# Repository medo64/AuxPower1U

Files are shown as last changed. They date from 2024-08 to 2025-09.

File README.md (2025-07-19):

# AuxPower1U

This project is 1U enclosed case with 5 DC outputs that are separately
controllable via front momentary switches with LEDs.

Features:
* 5 DC inputs (input 1 has to be 9-15V)
* 5 DC outputs
* 5 separate button controls
* voltage and current monitoring (9-60V, 0-8A, per channel)
* temperature monitoring
* OLED output
* 3 power supplies
* 2 power inputs (one for UPS, one for non-UPS)

## Usage

Different functionality can be triggered by different key press lengths:
* <5 seconds:    detail mode for channel (turns off automatically in 60 seconds)
* 5-10 seconds:  reset once button is released (or turns on if output was turned off)
* 10-13 seconds: turn off output permanently
* >13 seconds:   ignore press

## Uart Communication

Current usage will be written to UART twice a second. See example below:

    1: 11.98V 0.40A   4.77W [ON]
    2: 15.40V 3.10A  47.74W [ON]
    3: 15.42V 0.00A   0.00W [OFF]
    4: 15.42V 0.00A   0.00W [OFF]
    5: 54.13V 0.00A   0.00W [OFF]
    T: 23.4C

Each line consists of the space-separated readings. If line starts with a
channel number (1-5), what follows will be readings for the given channel of
voltage (V), current (A), and power (W) followed by a channel status. If line
starts with a letter T, what follows is a temperature. Each line will end with
`CRLF`.

Commands can be given to device by sending command code followed by a channel.
Available commands are:
* `D`: Disable
* `E`: Enable
* `R`: Reset
* `I`: Information

For example, to disable channel 2 use:

    D2

### 3.5mm Uart Connector

This is pinout, as viewed from board side (i.e. as marked on board).

| JST | 3.5mm  | Signal |
|-----|---|---|
|  1  | Tip | RX |
|  2  | Sleeve | GND |
|  3  | Ring | TX |

## Test Mode

To enter test mode, keep buttons 1 and 5 pressed while powering board on. Each
subsequent press will then cycle through channel and show voltage/current values
in higher than normal resolution.

## Components

* [MainController](src/MainController/README.md): Allowing for monitoring and resetting of lines
* [AuxFanController](https://github.com/medo64/AuxFanController): Optional board to run PWM fans dependant on temperature
* [DellPowerTrigger](https://github.com/medo64/DellPowerTrigger): Emulating Dell charger for 5.5x2.1mm input

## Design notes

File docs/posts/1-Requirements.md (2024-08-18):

As part of my home server setup, I have a few devices that have "free-floating"
power supplies. For example, my modem, my wireless PoE adapters, and a few test
boxes all have their power supply pushed into rack's nooks and crannies. Even
worse, since I want to have the capability to reset them, they are connected via
[ResetBox](https://www.medo64.com/resetbox/) (or its [type-C variant](https://www.medo64.com/2023/05/type-c-power-delivery-as-passive-poe-source/))
making cable situation even messier. It's way beyond time to sort that out!

In this blog series, I will go over what's needed to design a nice 1U box that
can fit all (or as many as I can) different power supplies togethe. Their
outputs should be resettable by physical buttons on the device's front. Since I
actually didn't finish the project as I'm typing this, expect the series not
only to last a few months while I gather all necessary equipment but also for my
"specifications" to shift slightly as I discover new things or rethink my old
ways.

At first, let's look at what power supplies we have currently:
* `12V` `25W`: Arris SURFboard Modem
* `22V-57V` `20W`: Mikrotik hAP ac
* `24-57V` `30W`: Mikrotik Audience
* `12-28V` `40W`: Mikrotik hAP ax3
* `19.5V` `65W`: Dell OptiPlex 3050 Micro
* `12-19V` `65W`: Intel NUC
* `54V` `15W`: Netgear GS305EPP (150W max)

If I squint hard enough, there are three distinct power supplies to use there;
the first one being a simple 12V power supply for modem. Power usage will be
really low on this one, so any hardware we place will run from it too.

To the second power supply, I had to give a bit more thought. Without question,
it has to run of the UPS but its target voltage is a bit of an unknown.
Currently, I am running my hAP ac and Audience from a 20V type-C power supply,
and Audience doesn't seem to love it as any minor transient causes reset. And
yes, officially Audience doesn't run that low, but I got lucky, I guess.
Previously, I was running my WiFi routers on 48V and both were fine with that;
so there are my two daya points. Considering other devices, I was leaning toward
selecting 24V as a second power supply.

However, that leaves my NetGear PoE switch a bit of a loner and outside of The
Box. For it, I would need to provide a proper 55V PoE power supply or at least
48V if stars align. The downside of this approach is that it leaves my Mikrotik
hAP ax3 either on 12V or for the last, non-UPS power supply. But the upside is
that it allows for a bit of future-proofing.

That leaves 2 non-UPS computers. Why are they not using UPS? Well, in my setup,
UPS power is really limited and is reserved for only two categories: my main
server and my Internet delivery devices (modem, router, WiFi APs). Anything else
just needs to handle a power loss. These two computers fall into "anything else"
category.

Intel NUC, we can already see, is flexible with a power supply specification.
When it comes to standard industrial voltages, it can handle both 12V and 15V
inputs. However, it Dell bretheren officially are not that flexible. While there
is a possibility my 3050 micro would work on 15V, anything higher is a no-go.
And since Dell authenticates its chargers, to figure this out, I'd need to trick
it first into accepting such voltage - all of which smells like another
sub-project. :)

If Dell doesn't want to cooperate, the only way forward would be to use one of
many [buck modules](https://www.amazon.com/dp/B07HRBT529/) intended for RVs that
brings 24V to 19V. I would really like to avoid this, if possible, because the
last thing I need is yet another power supply. However, it's good to have
options. And yes, ideally, I would find a 19V power supply; but I have a feeling
that finding one that can be properly mounted inside a 1U case is not going to
happen.

This brings us to the following rough power supply distribution (with a bit of
derating on power specification):
* `12V` `150W` (`100W` if I kick out Mikrotik hAP ax3 from my network):
  - `25W`: Arris SURFboard Modem
  - `25W`: Control boards
  - `40W`: Mikrotik hAP ax3

* `15V`/`19V`/`24V` `200W` (`150W` should be realistically more than fine):
  - `65W`: Dell OptiPlex 3050 Micro
  - `65W`: Intel NUC

* `48V`/`55V` `100W` (going higher than this might be good for the future PoE devices):
  - `20W`: Mikrotik hAP ac
  - `30W`: Mikrotik Audience
  - `15W`: Netgear GS30s5EPP

There is an alternative at a bit lower voltage:

* `12V` `75W`
  - `25W`: Arris SURFboard Modem
  - `25W`: Control boards

* `15V`/`19V`/`24V` `200W` (`150W` should be realistically more than fine):
  - `65W`: Dell OptiPlex 3050 Micro
  - `65W`: Intel NUC

* `24V` `150W`
  - `20W`: Mikrotik hAP ac
  - `30W`: Mikrotik Audience
  - `40W`: Mikrotik hAP ax3

* Out-of-scope
  - `15W`: Netgear GS30s5EPP

I am strongly leaning toward option 1, but option 2 is a good alternative. And
yes, Mikrotik is not as power hungry as it seems above; I've never seen it reach
its maximum power usage. However, since I really love my network, I use those
numbers to bring an additional margin to the dimensioning process. If I find a
nice power supply that's slightly below what I need, I will get it and not worry
about it. But, before I get to that, this fudged accounting provides more
visibility into what brings the most value.

For various protection circuits, I', going to rely onto power supplies to
protect themselves. Thus, at minimum, I expect any selected power supply to have
over-voltage, over-current, short-circuit, and over-temperature protection
built-in.

When it comes to controlling this, I would say that ability to reset my Modem
and WiFi is a must. And these can be two buttons as I want to be able to
separately restart modem. For the hAP ax3, I don't care as much since it has
"under test" status in my network at this time. But let's argue that it needs to
be a separate button. At this time, I do control each of my computers inside the
rack via smart plug so moving them into The Box, I might want to see a button
for each, but I wouldn't really mind if both go down at the same time. This
brings the total number of reset buttons to somewhere between a minimum of three
and a maximum of seven.

Lastly, this blog post leaves us with the following action items I will probably
get around to solving:
* Chck can Netgear GS305EPP work on 48V
* Make trigger board for Dell
* Check does Dell Optiplex 3050 Micro work on 15V

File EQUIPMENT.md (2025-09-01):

## Equipment Setup

| Machine | Connector | Specification | Tested | Using | UPS | Btn | Color  | Resistor |
|---|---|---|---|--- |-----|-----|---|---|
| Arris SURFboard SB6141 | 2.1x5.5mm | 12V 2A 25W | - | 12.0V |  Y  |  1  | Red |  1,200 Ω |
| Mikrotik Chateau Pro ax | 2.1x5.5mm PoE | 18-57V 18W | - | 54.0V |  Y  |  2  | Orange | 270 Ω |
| Mikrotik wAP ax | 2.1x5.5mm PoE | 12-57V 9W | - | 54.0V |  Y  |  2  | | |
| NetGear GS305EPP | 6.3x3.0mm | 54V 2.4A 138W | - | 54.0V |  Y  |  3  | Green  |  3,000 Ω |
| Dell OptiPlex 3050 B082MN2 | 4.5x3.0mm | 19.5V 65W | 14-20V | 16.0V |  N  |  4  | Blue |  1,000 Ω |
| Intel NUC 5i3RYB | 5.5x2.5mm | 12-19V 65W | - | 16.0V |  N  |  5  | White  |  1,500 Ω |

## Not Used

| Machine | Connector | Specification | Tested |
|---|---|---|---|
| Mikrotik hAP ax3 | 2.1x5.5mm | 18-28V 38W | - |

## Wire Colors

* DC GND      (Black  18 AWG)
* DC 12V      (Yellow 18 AWG)
* DC 15V      (Orange 18 AWG)
* DC 55V      (Red    18 AWG)
* AC Hot      (Blue   18 AWG)
* AC Neutral  (White  18 AWG)
* AC Ground   (Green  16 AWG)

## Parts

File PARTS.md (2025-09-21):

## AuxPower PCB

### Properties

| | |
|---|---|
| Size | 90.0 x 90.0 mm ~ 15.2 sqin |

### Parts

|  # | Part name | RefDes | Source |
|---:|---|---|---|
|  5 | AT PhotoMOS 6A 60V [AQZ202G] (SIP-4) | AT1-AT5  | 255-5699-ND |
|  5 | C 100nF X7R 50V (0805) | C1-c5 | 478-5311-1-ND |
|  2 | C 1uF X7R 25V (0805) | C6-C7 | 1276-1066-1-ND |
| 12 | DS LED Red (3mm) | DS1-DS12 | 754-1218-ND |
|  5 | J Phoenix MC 1,5/ 2-G-3,81 R/A (2w) | J1-J5 | ED2808-ND |
|  5 | J Phoenix MC 1,5/ 4-G-3,81 R/A (4w) | J6-J10 | ED2810-ND |
|  5 | J JST XH r/a (3w) | J11-J15  | 455-S3B-XH-A-ND |
|  1 | J JST XH (3w) | J16 | 455-2248-ND |
|  1 | J JST XH (4w) | J17 | 455-B4B-XH-A-ND |
|  5 | R 0.025 1% 3W (2512) | R1-R5 | CRA2512-FZ-R025ELFCT-ND |
|  5 | R 470 1% 0.125W (0805) | R6-R10 | RMCF0805FT470RCT-ND |
|  5 | R 1.5K 1% 0.125W (0805) | R11-R15  | RMCF0805FT1K50CT-ND |
| 20 | R 3.3K 1% 0.125W (0805) | R16-R35  | RMCF0805FT3K30CT-ND |
|  5 | R 6.19K 0.1% 0.125W (0805) | R36-R40  | P6.19KDACT-ND |
|  1 | R 6.80K 0.1% 0.125W (0805) | R41 | P6.8KDACT-ND |
|  1 | R 102K 0.1% 0.125W 1% (0805) | R42 | P102KDACT-ND |
|  5 | R 390K 0.1% 0.125W (0805) | R43-R47  | P390KDACT-ND |
|  5 | U CurrentMonitor [HV7801] (SOT23-5) | U1-U5 | HV7801K1-GCT-ND |
|  1 | U Micro [PIC18F26K83] (SOIC-28) | U6 | PIC18F26K83-I/SO-ND |
|  1 | U Expander I2C [PI4IOE5V6416LEX] (TSSOP-24) | U7 | PI4IOE5V6416LEXDICT-ND |
|  1 | U Temperature Analog 2% [MCP9701A] (SOT23-3) | U8 | MCP9701AT-E/TTCT-ND |
|  1 | VR Linear 5V 1A [AS7805ADTR-G1] (TO252-2) | VR1 | AS7805ADTR-G1DICT-ND |
|  5 | P Phoenix MC 1,5/ 2-ST-3,81 (2w) | P1-P5 | ED2875-ND |
|  5 | P Phoenix MC 1,5/ 4-ST-3,81 (4w) | P6-P10 | ED2877-ND |

### Pin Usage (PIC18F26K83)

|  # | Pin | ICSP | Function | Description |
|---:|:---:|---|---|---|
|  1 | RE3 | MCLR | | |
|  2 | RA0 | | ANA0 | Out 1: Current (ADC 1.024V 1:5) |
|  3 | RA1 | | ANA1 | Out 1: Voltage (ADC 1.024V 16mV/bit; 1:64) |
|  4 | RA2 | | ANA2 | Out 2: Current (ADC 1.024V 1:5) |
|  5 | RA3 | | ANA3 | Out 2: Voltage (ADC 1.024V 16mV/bit; 1:64) |
|  6 | RA4 | | ANA4 | Out 3: Current (ADC 1.024V 1:5) |
|  7 | RA5 | | ANA5 | Out 3: Voltage (ADC 1.024V 16mV/bit; 1:64) |
|  8 | Vss | GND  | - | - |
|  9 | RA7 | | ANA7 | Out 4: Current (ADC 1.024V 1:5) |
| 10 | RA6 | | ANA6 | Out 4: Voltage (ADC 1.024V 16mV/bit; 1:64) |
| 11 | RC0 | | ANC0 | Out 5: Current (ADC 1.024V 1:5) |
| 12 | RC1 | | ANC1 | Out 5: Voltage (ADC 1.024V 16mV/bit; 1:64) |
| 13 | RC2 | | ANC2 | Temperature sensor (ADC 2.048V 0.02C/bit)  |
| 14 | RC3 | | ANC3 | In 1: Voltage  (ADC 1.024V 4mV/bit; 1:16)  |
| 15 | RC4 | | C4 | Out 5: Control |
| 16 | RC5 | | C5 | Out 4: Control |
| 17 | RC6 | | C6 | Out 3: Control |
| 18 | RC7 | | C7 | Out 2: Control |
| 19 | Vss | GND  | - | - |
| 20 | Vdd | 5V | - | - |
| 21 | RB0 | | B0 | Out 1: Control |
| 22 | RB1 | | I2C SCL  | I2C |
| 23 | RB2 | | I2C SDA  | I2C |
| 24 | RB3 | | B3 | LED: Activity |
| 25 | RB4 | | UART TX  | UART |
| 26 | RB5 | | UART RX  | UART |
| 27 | RB6 | CLK  | | |
| 28 | RB7 | DAT  | | |

### Pin Usage (PI4IOE5V6416)

|  # | Pin | ICSP | Description |
|---:|:-----:|---|---|
|  1 | INT | | - |
|  2 | Vdd/I | 5V | - |
|  3 | RESET | | - |
|  4 | P0_0  | | ~~Out 1: Control~~ |
|  5 | P0_1  | | ~~Out 2: Control~~ |
|  6 | P0_2  | | ~~Out 3: Control~~ |
|  7 | P0_3  | | ~~Out 4: Control~~ |
|  8 | P0_4  | | ~~Out 5: Control~~ |
|  9 | P0_5  | | |
| 10 | P0_6  | | Button 5: ~Switch  |
| 11 | P0_7  | | Button 5: LED |
| 12 | Vss | GND  | - |
| 13 | P1_0  | | Button 4: LED |
| 14 | P1_1  | | Button 4: ~Switch  |
| 15 | P1_2  | | Button 3: LED |
| 16 | P1_3  | | Button 3: ~Switch  |
| 17 | P1_4  | | Button 2: LED |
| 18 | P1_5  | | Button 2: ~Switch  |
| 19 | P1_6  | | Button 1: LED |
| 20 | P1_7  | | Button 1: ~Switch  |
| 21 | Vss | GND  | - |
| 22 | SCL | | I2C SCL |
| 23 | SDA | | I2C SDA |
| 24 | Vdd/P | 5V | - |

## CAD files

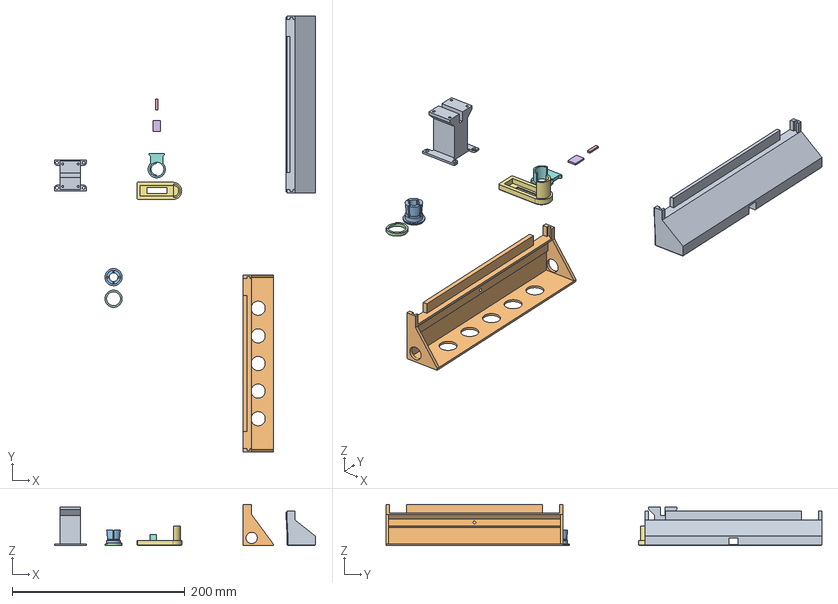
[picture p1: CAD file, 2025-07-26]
models/Cheval-PF19AL1UD1/AuxPower1U.FCStd
302.5 x 505.0 x 48.0 mm
PsuRailBack
PsuRailFront
AcGrommetBase
AcGrommetRing
OledBraceNarrow
OledBraceWide
OledBraceOuter
OledBraceInner
Fan

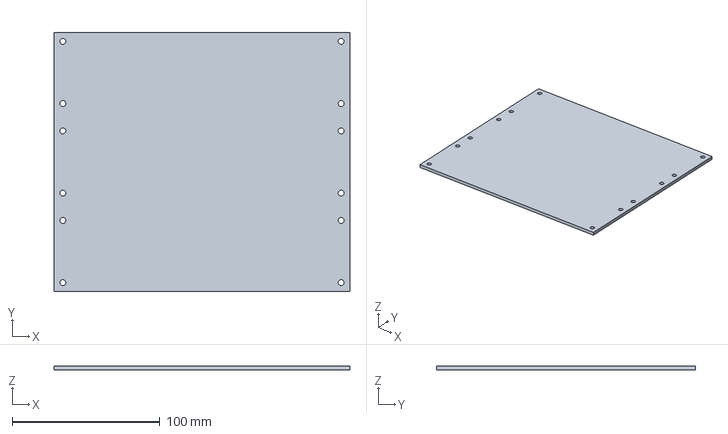
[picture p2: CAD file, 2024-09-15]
src/case/AuxPower1U Aluminium Plate.FCStd
200.0 x 175.0 x 3.00 mm

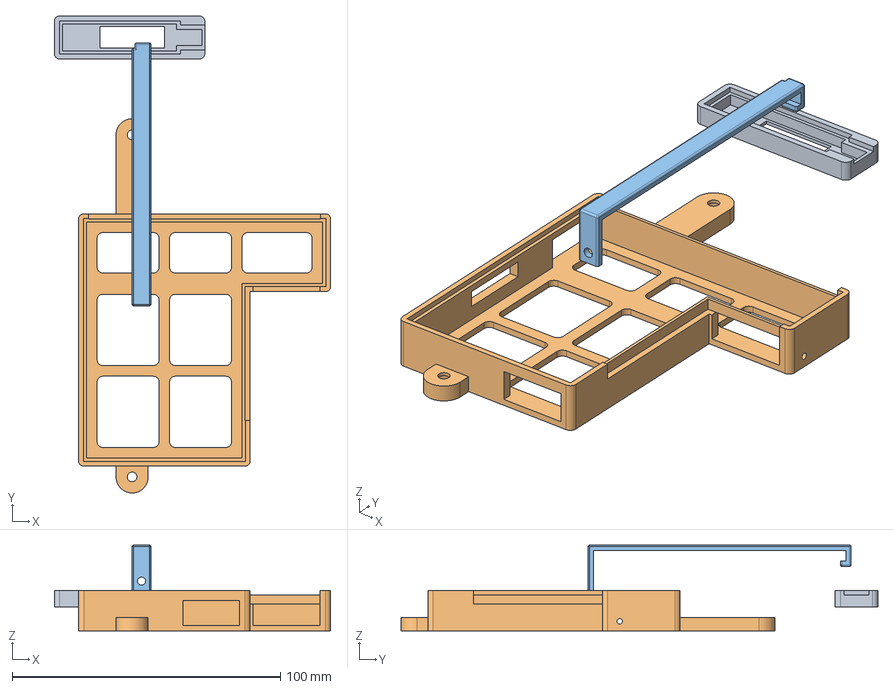
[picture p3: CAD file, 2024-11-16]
src/case/Bud-PRM14460/AuxPower1U PCBs.FCStd
103.0 x 177.7 x 32.0 mm
FanController
MainController
MainControllerBrace

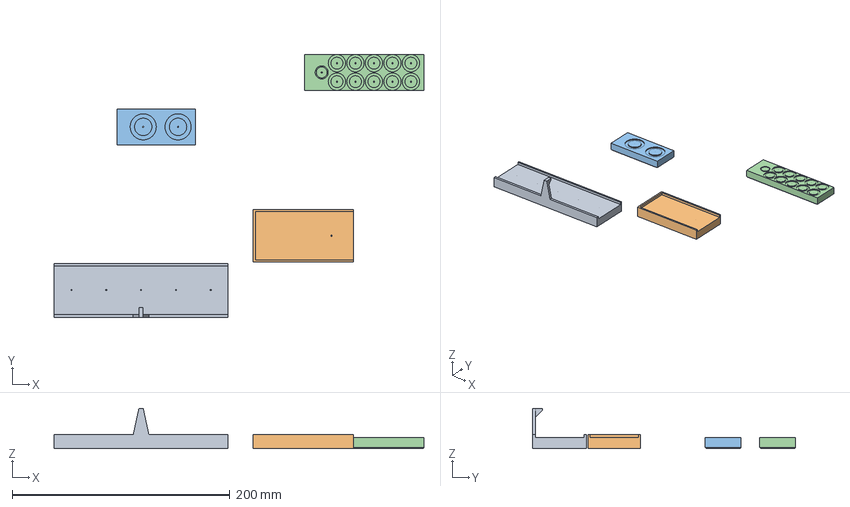
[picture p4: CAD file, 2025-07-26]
src/case/Cheval-PF19AL1UD1/AuxPower1U-Template.FCStd
340.0 x 241.7 x 37.0 mm
Buttons
Oled
AC
DC

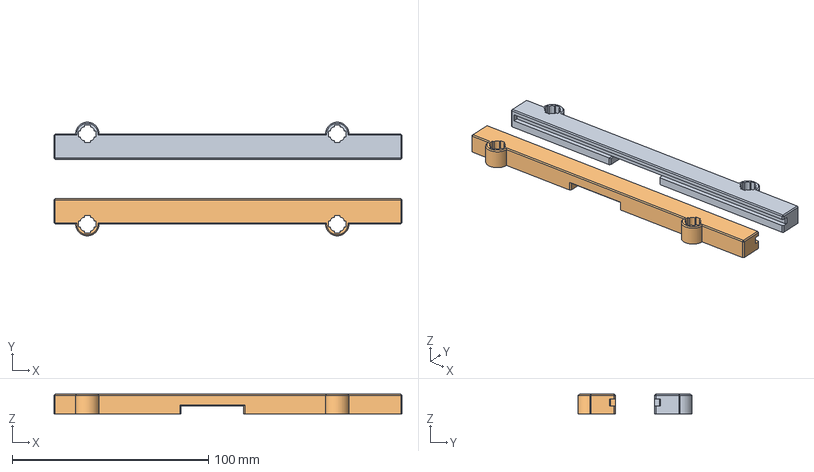
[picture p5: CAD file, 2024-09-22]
src/case/Bud-PRM14460/AuxPower1U PSRail.FCStd
177.4 x 58.0 x 10.0 mm
RailL
RailR

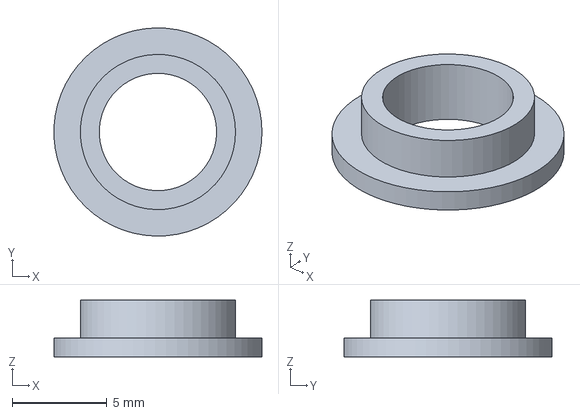
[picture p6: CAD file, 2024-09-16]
src/case/Bud-PRM14460/AuxPower1U Fixup.FCStd
11.0 x 11.0 x 3.00 mm

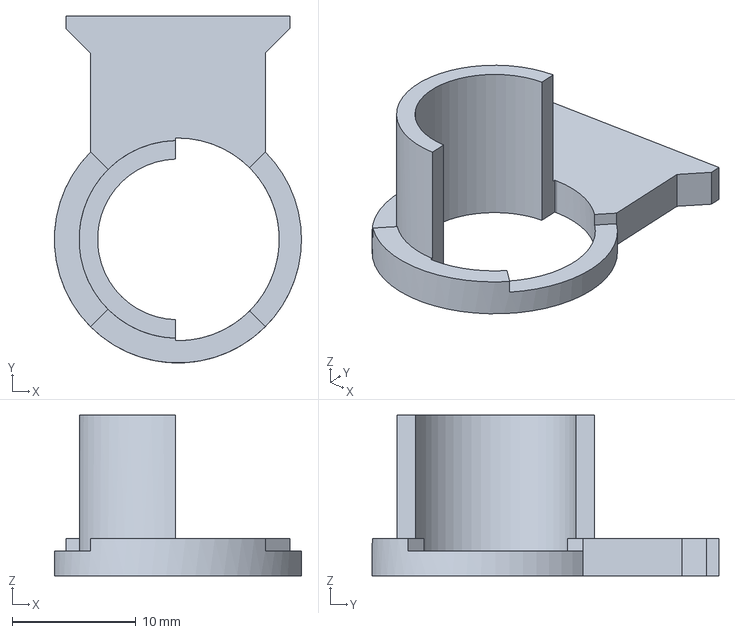
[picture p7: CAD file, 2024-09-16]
src/case/Bud-PRM14460/AuxPower1U OLED.FCStd
20.0 x 28.1 x 13.0 mm

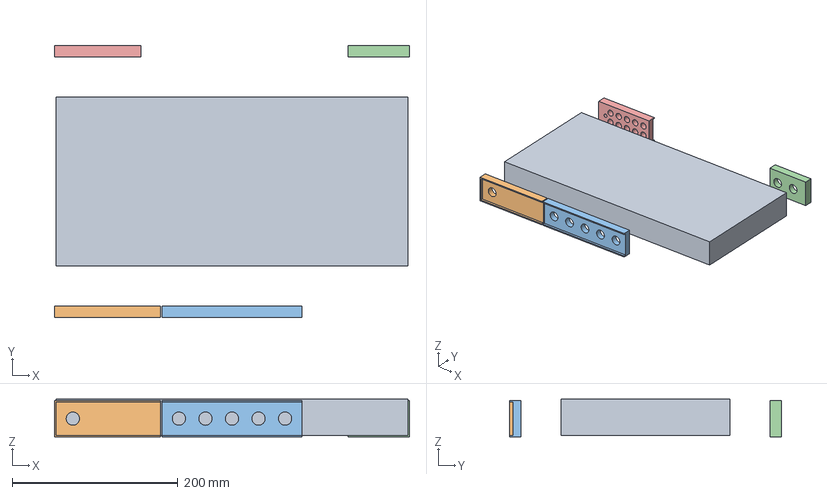
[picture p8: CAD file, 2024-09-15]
src/case/Bud-PRM14460/AuxPower1U Drill Template.FCStd
427.9 x 328.0 x 45.7 mm
Case
Front-Oled-16mm
Front-Buttons-16mm
Back-AC-16mm
Back-DC-11mm-6mm

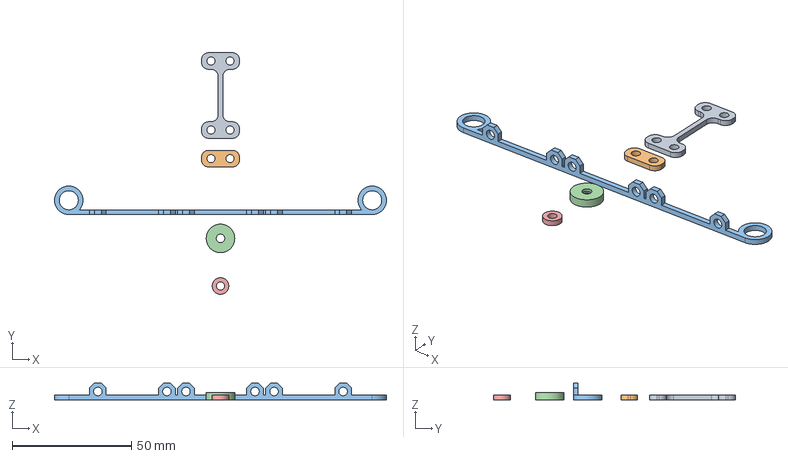
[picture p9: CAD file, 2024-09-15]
src/case/Bud-PRM14460/AuxPower1U Fan.FCStd
139.4 x 101.5 x 7.00 mm
LongBrace
ShortBrace
BackBrace
BraceCap
SingleBrace

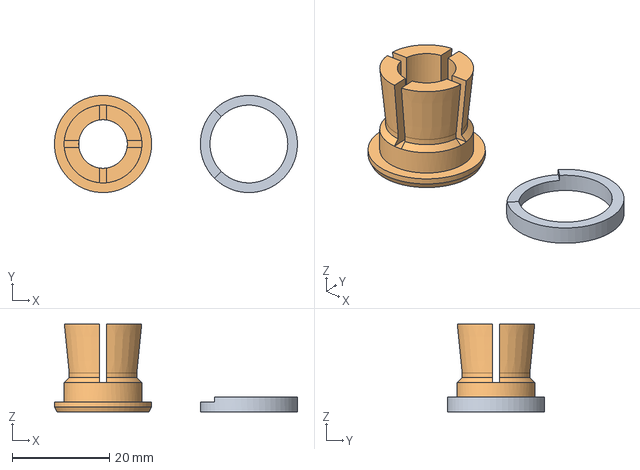
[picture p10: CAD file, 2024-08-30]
src/case/Bud-PRM14460/AuxPower1U AC Grommet.FCStd
50.0 x 20.0 x 18.0 mm
Ring
Base

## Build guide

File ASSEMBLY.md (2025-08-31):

## Enclosure Assembly

|  # | Part | Source |
|---:|---|---|
|  1 | Cheval PF19AL1UD1 | https://www.amazon.com/dp/B0F9W3KV6V |
| 10 | Panel DC 5.5x2.1mm Φ11mm | https://www.digikey.com/en/products/detail/tensility-international-corp/10-03609/12090912 |
| 20 | Crimp Terminal E7508 | |
|  1 | Panel Audio TRS 3.5mm Φ10mm | https://www.digikey.com/en/products/detail/tensility-international-corp/10-02844/11193625 |
|  1 | Spacer M3x30mm | https://www.amazon.com/dp/B0CZ3YTVWX |
|  1 | Machine screw M3x10 | |
|  1 | PSU rail back | 3D Printer |
|  1 | PSU rail front | 3D Printer |

### Power Supply Subassembly

|  # | Part | Source |
|---:|---|---|
|  1 | Power supply UHP-200-12 | https://www.digikey.com/en/products/detail/mean-well-usa-inc/UHP-200-12/7707237 |
|  1 | Power supply UHP-200-15 | https://www.digikey.com/en/products/detail/mean-well-usa-inc/UHP-200-15/7707238 |
|  1 | Power supply UHP-200-55 | https://www.digikey.com/en/products/detail/mean-well-usa-inc/UHP-200-55/13245670 |
|  1 | Aluminium plate 200x175 | SendCutSend (200x175 mm, 12 4mm holes, 6061 3.2mm, deburring) |
| 12 | Machine screw M3x6 | |
| 12 | Nut M3 | |
| 24 | Washer M3x6x0.5 | |
| | Heat sink compound | https://www.super-lube.com/silicone-heat-sink-compound-98003 |

### Fan Subassembly

|  # | Part | Source |
|---:|---|---|
|  2 | Fan 12V 3628 | https://www.aliexpress.us/item/3256804458184414.html |
|  4 | Fan screw | |
|  1 | Machine screw M3x8 | |
|  2 | Fan holder | 3D Printer |

### AC Power Wiring

|  # | Part | Source |
|---:|---|---|
|  2 | Power Cable AWG 18 | |
|  3 | Wago 221-413 | |
|  2 | Clamp 16mm | https://www.amazon.com/dp/B0C4V84F1V |
|  9 | Ring Terminal RV1.25-4s | https://www.aliexpress.us/item/3256805890650511.html |
| | Wire AWG 18 | |
|  2 | AC Grommet | 3D Printer |

### Buttons Subassembly

|  # | Part | Source |
|---:|---|---|
|  5 | Button 16mm | https://www.aliexpress.us/item/3256804791551109.html |
| 20 | Ferrule E7508 0.75mm² | |

### DC Power Wiring

|  # | Part | Source |
|---:|---|---|
| 12 | Ring Terminal RV1.25-4s | https://www.aliexpress.us/item/3256805890650511.html |
| 12 | Crimp Terminal E7508 | |
| | Wire AWG 18 | |

### OLED Subassembly

|  # | Part | Source |
|---:|---|---|
|  1 | OLED 128x32 | |
|  1 | Clamp 16mm | https://www.amazon.com/dp/B0C4V84F1V |
|  1 | OLED Grommet | 3D Printer |

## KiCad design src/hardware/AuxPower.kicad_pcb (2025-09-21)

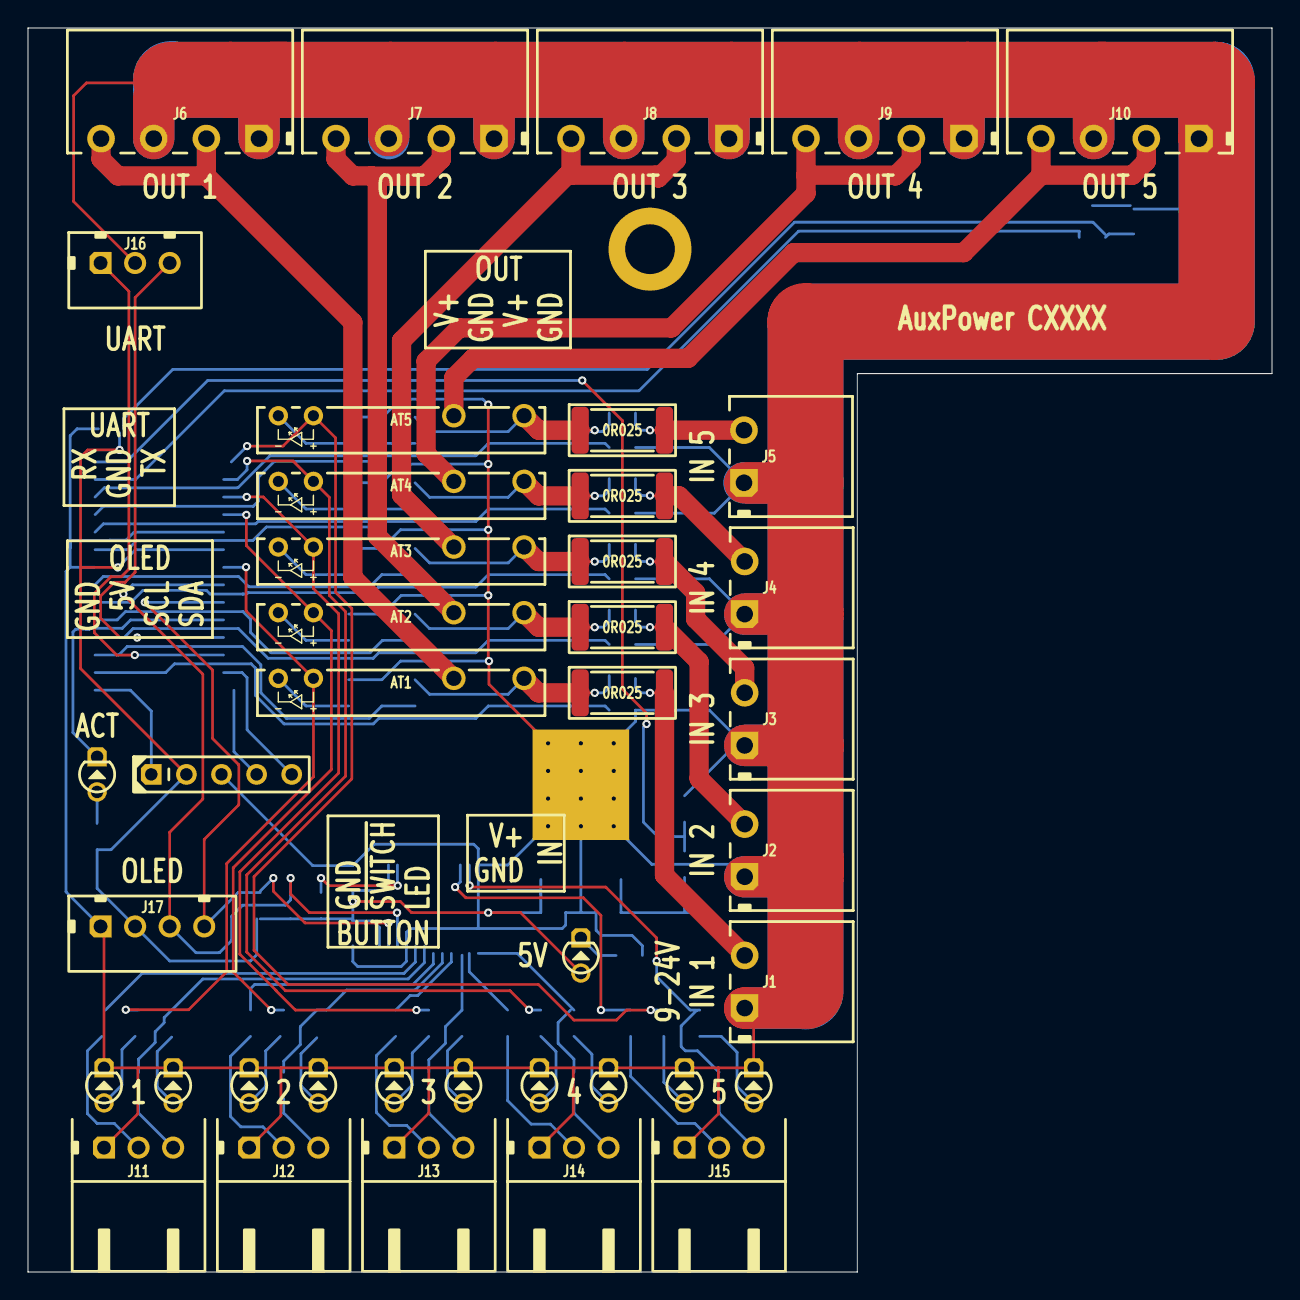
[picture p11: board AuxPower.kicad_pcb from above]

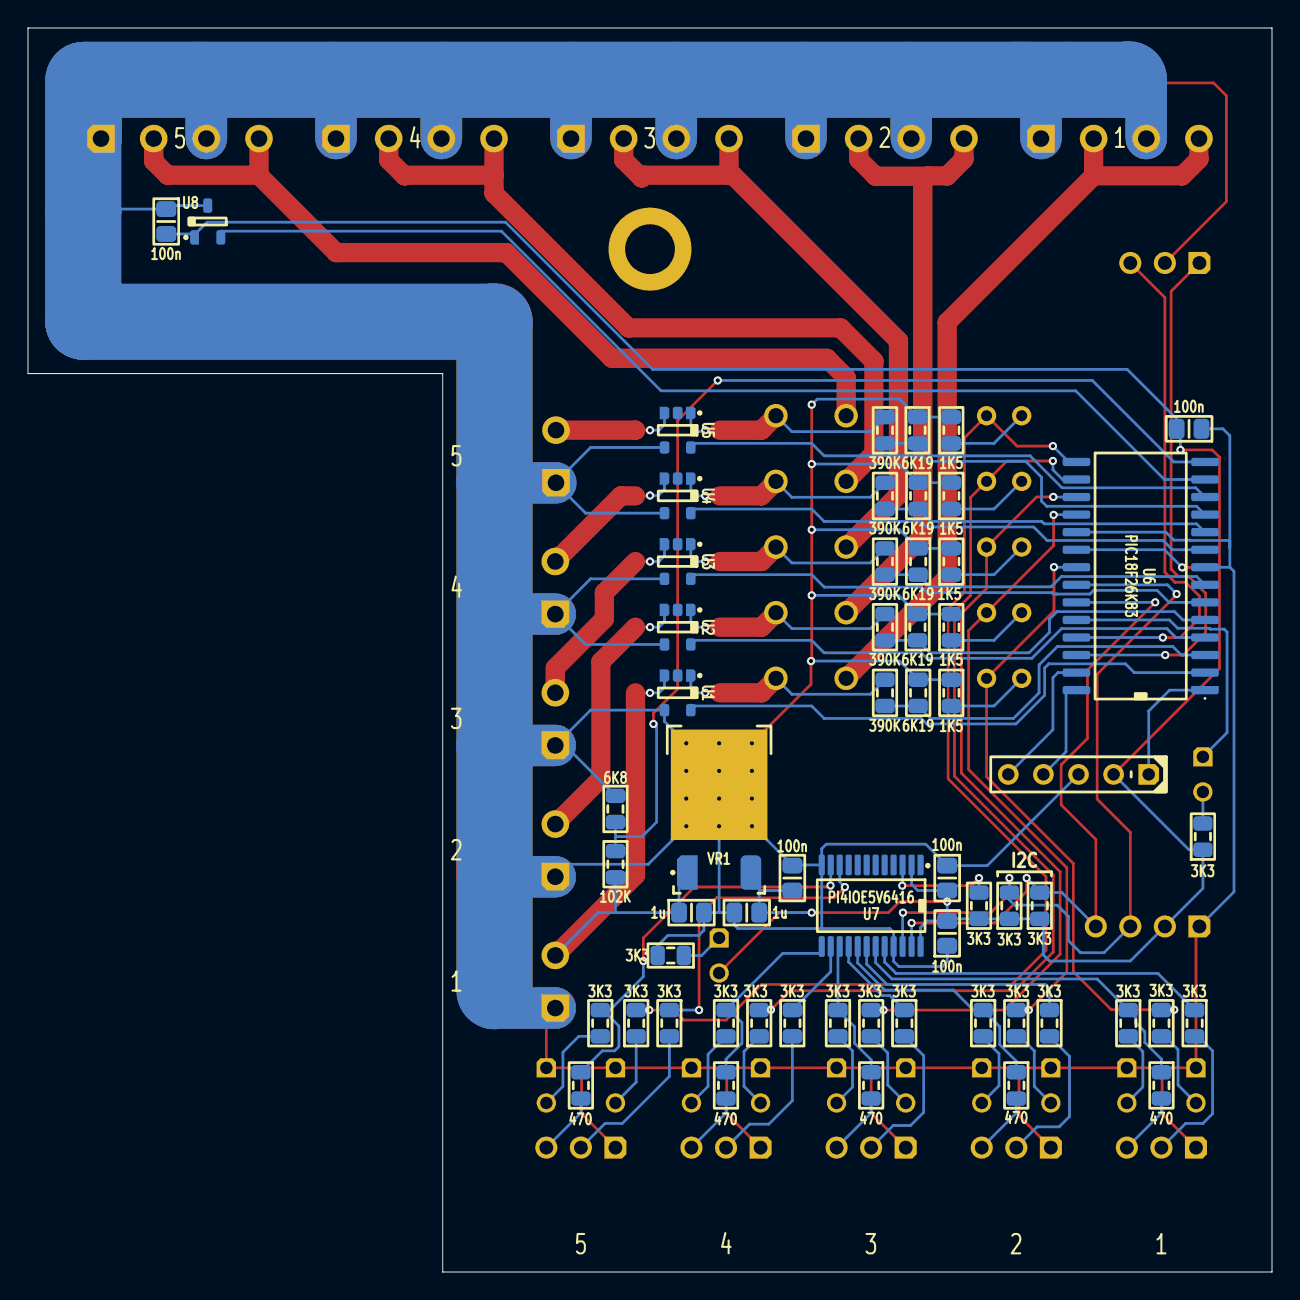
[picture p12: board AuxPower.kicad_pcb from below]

Board: 2 copper layers, 90.0 x 90.0 mm, 99 parts (58 on the bottom side), 80 nets.

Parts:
AT1, AT2, AT3, AT4, AT5: AQZ202G; AT PhotoMOS [AQZ202G] (SIP-4)
C1, C2, C3, C4, C5: 100n; C (0805)
C6, C7: 1u; C (0805)
DS1, DS2, DS3, DS4, DS5, DS6, DS7, DS8, DS9, DS10, DS11, DS12: LED; DS (D3.0)
ICSP: Microchip PIC; ICSP PIC Pogo DS (5w)
J1, J2, J3, J4, J5: MC 1,5/2; J Phoenix MC (2w)
J6, J7, J8, J9, J10: MC 1,5/4; J Phoenix MC (4w)
J11, J12, J13, J14, J15: S3B-XH-A; J JST XH S (3w)
J16: B3B-XH-A; J JST XH B [UART] (3w)
J17: B4B-XH-A; J JST XH B [I2C] (4w)
MH1: M3; MH M3
R1, R2, R3, R4, R5: 0R025; R (2512)
R6, R7, R8, R9, R10: 470; R (0805)
R11, R12, R13, R14, R15: 1K5; R (0805)
R16, R17, R18, R19, R20, R21, R22, R23, R24, R25, R26, R27, R28, R29, R30, R31, R32, R33, R34, R35: 3K3; R (0805)
R36, R37, R38, R39, R40: 6K19; R (0805)
R41: 6K8; R (0805)
R42: 102K; R (0805)
R43, R44, R45, R46, R47: 390K; R (0805)
U1, U2, U3, U4, U5: HV7801; U CurrentMonitor [HV7801] (SOT23-5)
U6: PIC18F26K83; U Micro [PIC18F26K83] (SOIC-28)
U7: PI4IOE5V6416; U Expander I2C [PI4IOE5V6416LEX] (TSSOP-24)
U8: MCP9701; U Temperature Analog [MCP9701] (SOT23-3)
VR1: AS7805ADTR; VR Linear 5V 1000mA [AS7805ADTR-G1] (TO252-2')

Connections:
5V: C1.2, C2.1, C3.1, C4.1, C5.1, C6.2, DS11.2, ICSP.2, J17.2, R16.2, R27.2, R34.2, R35.2, U6.20, U7.2, U7.24, U8.1, VR1.3
ADC_CURRENT1: U1.5, U6.2
ADC_CURRENT2: U2.5, U6.4
ADC_CURRENT3: U3.5, U6.6
ADC_CURRENT4: U4.5, U6.9
ADC_CURRENT5: U5.5, U6.11
ADC_TEMPERATURE: U6.13, U8.2
ADC_VOLTAGE1: R36.1, R43.1, U6.3
ADC_VOLTAGE2: R37.1, R44.2, U6.5
ADC_VOLTAGE3: R38.1, R45.2, U6.7
ADC_VOLTAGE4: R39.1, R46.2, U6.10
ADC_VOLTAGE5: R40.1, R47.2, U6.12
ADC_VOLTAGE_IN: R41.1, R42.2, U6.14
BUTTON1_LED: J11.3, R6.1
BUTTON1_SWITCH: J11.2, R29.1
BUTTON2_LED: J12.3, R7.1
BUTTON2_SWITCH: J12.2, R30.1
BUTTON3_LED: J13.3, R8.1
BUTTON3_SWITCH: J13.2, R31.1
BUTTON4_LED: J14.3, R9.1
BUTTON4_SWITCH: J14.2, R32.1
BUTTON5_LED: J15.3, R10.1
BUTTON5_SWITCH: J15.2, R33.1
EXPANDER_RESET: R16.1, U7.3
GND: C1.1, C2.2, C3.2, C4.2, C5.2, C6.1, C7.1, DS1.1, DS2.1, DS3.1, DS4.1, DS5.1, DS6.1, DS7.1, DS8.1, DS9.1, DS10.1, ICSP.3, J1.1, J2.1, J3.1, J4.1, J5.1, J6.1, J6.3, J7.1, J7.3, J8.1, J8.3, J9.1, J9.3, J10.1, J10.3, J11.1, J12.1, J13.1, J14.1, J15.1, J16.2, J17.1, R11.2, R12.1, R13.1, R14.1, R15.1, R26.1, R36.2, R37.2, R38.2, R39.2, R40.2, R41.2, U1.4, U2.4, U3.4, U4.4, U5.4, U6.8, U6.19, U7.12, U7.21, U8.3, VR1.2
I2C_SCL: J17.3, R35.1, U6.22, U7.22
I2C_SDA: J17.4, R34.1, U6.23, U7.23
ICSP_CLK: ICSP.5, U6.27
ICSP_DAT: ICSP.4, U6.28
ICSP_VPP: ICSP.1, U6.1
INPUT1: C7.2, J1.2, R1.1, R42.1, U1.3, VR1.1
INPUT1': AT1.4, R1.2, R43.2, U1.1
INPUT2: J2.2, R2.1, U2.3
INPUT2': AT2.4, R2.2, R44.1, U2.1
INPUT3: J3.2, R3.1, U3.3
INPUT3': AT3.4, R3.2, R45.1, U3.1
INPUT4: J4.2, R4.1, U4.3
INPUT4': AT4.4, R4.2, R46.1, U4.1
INPUT5: J5.2, R5.1, U5.3
INPUT5': AT5.4, R5.2, R47.1, U5.1
IN_BUTTON1_SWITCH: R29.2, U7.20
IN_BUTTON2_SWITCH: R30.2, U7.18
IN_BUTTON3_SWITCH: R31.2, U7.16
IN_BUTTON4_SWITCH: R32.2, U7.14
IN_BUTTON5_SWITCH: R33.2, U7.10
LED_ACTIVITY: DS12.2, R27.1
LED_BUTTON_INT_1: DS1.2, R28.1
LED_BUTTON_INT_2: DS2.2, R22.1
LED_BUTTON_INT_3: DS3.2, R23.1
LED_BUTTON_INT_4: DS4.2, R24.1
LED_BUTTON_INT_5: DS5.2, R25.1
LED_OUTPUT1: DS6.2, R17.2
LED_OUTPUT2: DS7.2, R18.2
LED_OUTPUT3: DS8.2, R19.2
LED_OUTPUT4: DS9.2, R20.2
LED_OUTPUT5: DS10.2, R21.2
LED_POWER: DS11.1, R26.2
OUTPUT1: AT1.3, J6.2, J6.4
OUTPUT2: AT2.3, J7.2, J7.4
OUTPUT3: AT3.3, J8.2, J8.4
OUTPUT4: AT4.3, J9.2, J9.4
OUTPUT5: AT5.3, J10.2, J10.4
OUT_ACTIVITY: DS12.1, U6.24
OUT_BUTTON1_LED: R6.2, R28.2, U7.19
OUT_BUTTON2_LED: R7.2, R22.2, U7.17
OUT_BUTTON3_LED: R8.2, R23.2, U7.15
OUT_BUTTON4_LED: R9.2, R24.2, U7.13
OUT_BUTTON5_LED: R10.2, R25.2, U7.11
OUT_OUTPUT1: AT1.2, R17.1, U6.21
OUT_OUTPUT1': AT1.1, R11.1
OUT_OUTPUT2: AT2.2, R18.1, U6.18
OUT_OUTPUT2': AT2.1, R12.2
OUT_OUTPUT3: AT3.2, R19.1, U6.17
OUT_OUTPUT3': AT3.1, R13.2
OUT_OUTPUT4: AT4.2, R20.1, U6.16
OUT_OUTPUT4': AT4.1, R14.2
OUT_OUTPUT5: AT5.2, R21.1, U6.15
OUT_OUTPUT5': AT5.1, R15.2
UART_RX: J16.1, U6.26
UART_TX: J16.3, U6.25

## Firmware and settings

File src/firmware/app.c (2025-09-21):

#include <xc.h>
#include <stdbool.h>
#include <stdint.h>
#include "app.h"
#include "adc.h"
#include "i2c_master.h"
#include "io.h"
#include "ioex.h"
#include "measurement.h"
#include "oled.h"
#include "pps.h"
#include "ticker.h"
#include "settings.h"
#include "ssd1306.h"
#include "uart.h"
#include "uartbuffers.h"

#define DEPTH_SUMMARY          0
#define DEPTH_DETAILS          1
#define DEPTH_PENDING_RESET    2
#define DEPTH_PENDING_OFF      3
#define DEPTH_PENDING_NOTHING  4

#define TICKS_CLOSE_DETAILS    60 * 24
#define TICKS_IGNORE_DETAILS         6
#define TICKS_GOTO_RESET        3 * 24
#define TICKS_WAIT_RESET        3 * 24
#define TICKS_WAIT_OFF          3 * 24
#define TICKS_DURATION_RESET    5 * 24
#define TICKS_DISPLAY_OFF     300 * 24


void fillUartFromChannel(uint8_t index, uint16_t voltage, uint16_t current, bool isOn);
void fillUartFromTemperature(uint16_t temperature);

uint8_t enableOutputMask(const uint8_t channel, const uint8_t currOutputs);
uint8_t disableOutputMask(const uint8_t channel, const uint8_t currOutputs);
uint8_t toggleOutputMask(const uint8_t channel, const uint8_t currOutputs);
uint8_t resetOutput(const uint8_t channel, const uint8_t currOutputs);


void main(void) {
    init();
    pps_init();
    ticker_init();

    io_init();

    io_led_activity_on();
    uart_init();
    uart_writeString("AuxPower\r\n");
    io_led_activity_off();

    CLRWDT();
    io_led_activity_on();
    i2c_master_init();
    __delay_ms(50);
    ioex_init();
    oled_init();
    oled_splash();
    io_led_activity_off();

    // setup config
    CLRWDT();
    settings_init();

    // config: outputs
    uint8_t nextOutputs = settings_outputs_get();
    uint8_t currOutputs = nextOutputs | 0b10000000;  // just to force change when first ran

    // config: cutoff currents
    uint16_t cutoffCurrent1Fast, cutoffCurrent2Fast, cutoffCurrent3Fast, cutoffCurrent4Fast, cutoffCurrent5Fast;
    settings_cutoff_current_get(&cutoffCurrent1Fast, &cutoffCurrent2Fast, &cutoffCurrent3Fast, &cutoffCurrent4Fast, &cutoffCurrent5Fast);

    // setup measurement
    CLRWDT();
    uint16_t voltage1, current1, voltage2, current2, voltage3, current3, voltage4, current4, voltage5, current5, temperature;
    measurement_init(cutoffCurrent1Fast, cutoffCurrent2Fast, cutoffCurrent3Fast, cutoffCurrent4Fast, cutoffCurrent5Fast);

    // check whether to go to test mode (button 1 and 5))
    bool switch1State, switch2State, switch3State, switch4State, switch5State;
    ioex_button_switch_getAll(&switch1State, &switch2State, &switch3State, &switch4State, &switch5State);
    if (switch1State && !switch2State && !switch3State && !switch4State && switch5State) {
        test();
        return;
    }

    // state variables
    uint8_t currDepth = DEPTH_SUMMARY;  // 0: summary; 1: details; 2: prepare reset; 3: reset; 4: shutdown
    uint8_t nextDepth = DEPTH_SUMMARY;
    uint16_t currDepthTicks = 0;        // how long has system been at the current level
    uint16_t currDepthButtonTicks = 0;  // how many ticks passed with current buttons at current level
    uint16_t lastActionTicks = 0;       // how many ticks passed since last button press
    uint8_t currChannel = 0;            // 1-5: selected channel
    uint8_t currButtonMask = 0;         // currently pressed buttons
    uint8_t prevButtonMask = 0;         // previously pressed buttons
    bool prevBlinking = false;
    uint8_t tickCounter = 0;

    // main loop
    while(true) {
        CLRWDT();

        // send UART data
        if (UartTxBufferStart < UartTxBufferCount) {  // send data if in buffer
            if (uart_tryWriteByte(UartTxBuffer[UartTxBufferStart])) {
                UartTxBufferStart++;
            }
        }

        // receive UART commands
        uint8_t rxData;
        while (uart_tryReadByte(&rxData)) {
            if ((rxData == '\n') || (rxData == '\r')) {
                bool isNok = true;
                if (UartRxBufferCount == 2) {
                    uint8_t channelIndex = UartRxBuffer[1] - 0x30;
                    if ((channelIndex >= 1) && (channelIndex <= 5)) {
                        switch (UartRxBuffer[0]) {
                            case 'D':
                            case 'd':
                                nextOutputs = disableOutputMask(channelIndex, nextOutputs);
                                isNok = false;
                                break;

                            case 'E':
                            case 'e':
                                nextOutputs = enableOutputMask(channelIndex, nextOutputs);
                                isNok = false;
                                break;
                               break;

                            case 'I':
                            case 'i':
                                currChannel = channelIndex;
                                nextDepth = DEPTH_DETAILS;
                                break;

                            case 'R':
                            case 'r':
                                nextOutputs = resetOutput(channelIndex, nextOutputs);
                                isNok = false;
                                break;
                        }
                    }
                } else if  (UartRxBufferCount == 1) {
                    switch (UartRxBuffer[0]) {
                        case 'I':
                        case 'i':
                            nextDepth = DEPTH_SUMMARY;
                            isNok = false;
                    }
                } else if  (UartRxBufferCount == 0) {
                    isNok = false;  // ignore empty
                }
                CLRWDT();
                if (isNok) {
                    UartRxBufferCount = 0;
                    uartbuffers_txAppend('!');
                    uartbuffers_txAppend('\r');
                    uartbuffers_txAppend('\n');
                }
                UartRxBufferCount = 0;
            } else {
                uartbuffers_rxAppend(rxData);
            }
        }

        if (ticker_hasTicked()) {  // 24th of a second
            io_led_activity_off();
            tickCounter++;
            if (tickCounter == 24) { tickCounter = 0; }
            currDepthTicks++;
            lastActionTicks++;

            // measure each tick
            measurement_basic(&nextOutputs, &voltage1, &current1, &voltage2, &current2, &voltage3, &current3, &voltage4, &current4, &voltage5, &current5, &temperature);

            // check if state needs change
            if (currOutputs != nextOutputs) {
                currOutputs = nextOutputs;
                bool nextState1 = (currOutputs & 0b00001) != 0;
                bool nextState2 = (currOutputs & 0b00010) != 0;
                bool nextState3 = (currOutputs & 0b00100) != 0;
                bool nextState4 = (currOutputs & 0b01000) != 0;
                bool nextState5 = (currOutputs & 0b10000) != 0;
                ioex_output_setAll(nextState1, nextState2, nextState3, nextState4, nextState5);      // set outputs
                ioex_button_led_setAll(nextState1, nextState2, nextState3, nextState4, nextState5);  // set LEDs
                settings_outputs_set(nextOutputs);                                                   // save for the next startup
            }

            // check buttons each tick
            ioex_button_switch_getAll(&switch1State, &switch2State, &switch3State, &switch4State, &switch5State);
            prevButtonMask = currButtonMask;
            currButtonMask = 0;
            uint8_t currButtonMaskCount = 0;
            if (switch1State) { currButtonMask |= 0b00001; currButtonMaskCount++; }
            if (switch2State) { currButtonMask |= 0b00010; currButtonMaskCount++; }
            if (switch3State) { currButtonMask |= 0b00100; currButtonMaskCount++; }
            if (switch4State) { currButtonMask |= 0b01000; currButtonMaskCount++; }
            if (switch5State) { currButtonMask |= 0b10000; currButtonMaskCount++; }
            if ((currButtonMaskCount == 1) && (currButtonMask == prevButtonMask)) { currDepthButtonTicks++; } else { currDepthButtonTicks = 0; }
            if (currButtonMask != prevButtonMask) { lastActionTicks = 0; }

            // figure out button mask
            uint8_t currChannelButtonMask;
            switch (currChannel) {
                case 1: currChannelButtonMask = 0b00001; break;
                case 2: currChannelButtonMask = 0b00010; break;
                case 3: currChannelButtonMask = 0b00100; break;
                case 4: currChannelButtonMask = 0b01000; break;
                case 5: currChannelButtonMask = 0b10000; break;
                default: currChannelButtonMask = 0; break;
            }

            // state changes
            if (currDepth != nextDepth) {
                currDepth = nextDepth;
                currDepthTicks = 0;
                currDepthButtonTicks = 0;
                tickCounter = 0;  // force update
            }

            bool currBlinking = false;
            if (currDepth == DEPTH_PENDING_RESET) {
                switch (currChannel) {  // blinking while waiting for reset (12/s)
                    case 1: ioex_button_led_toggle1(); break;
                    case 2: ioex_button_led_toggle2(); break;
                    case 3: ioex_button_led_toggle3(); break;
                    case 4: ioex_button_led_toggle4(); break;
                    case 5: ioex_button_led_toggle5(); break;
                }
                currBlinking = true;
            } else if (currDepth == DEPTH_PENDING_OFF) {
                if ((tickCounter % 6) == 0) {  // blinking while checking off is (4/s)
                    switch (currChannel) {
                        case 1: ioex_button_led_toggle1(); break;
                        case 2: ioex_button_led_toggle2(); break;
                        case 3: ioex_button_led_toggle3(); break;
                        case 4: ioex_button_led_toggle4(); break;
                        case 5: ioex_button_led_toggle5(); break;
                    }
                    currBlinking = true;
                }
            } else if (currDepth == DEPTH_DETAILS) {
                if ((currButtonMask > 0) && ((tickCounter % 12) == 0)) {  // blink while waiting for reset (1/s)
                    switch (currChannel) {
                        case 1: ioex_button_led_toggle1(); break;
                        case 2: ioex_button_led_toggle2(); break;
                        case 3: ioex_button_led_toggle3(); break;
                        case 4: ioex_button_led_toggle4(); break;
                        case 5: ioex_button_led_toggle5(); break;
                    }
                    currBlinking = true;
                }
            }
            if (prevBlinking != currBlinking) {
                if (!currBlinking && prevBlinking) {  // reset LEDs if blinking is over
                    ioex_button_led_setAll(
                        (currOutputs & 0b00001) != 0,
                        (currOutputs & 0b00010) != 0,
                        (currOutputs & 0b00100) != 0,
                        (currOutputs & 0b01000) != 0,
                        (currOutputs & 0b10000) != 0
                    );
                }
                prevBlinking = currBlinking;
            }

            switch (currDepth) {
                case DEPTH_SUMMARY: {
                    switch (currButtonMask) {  // switch to details
                        case 0b00001: nextDepth = DEPTH_DETAILS; currChannel = 1; break;
                        case 0b00010: nextDepth = DEPTH_DETAILS; currChannel = 2; break;
                        case 0b00100: nextDepth = DEPTH_DETAILS; currChannel = 3; break;
                        case 0b01000: nextDepth = DEPTH_DETAILS; currChannel = 4; break;
                        case 0b10000: nextDepth = DEPTH_DETAILS; currChannel = 5; break;
                    }
                } break;

                case DEPTH_DETAILS: {
                    if (currButtonMask == 0) {  // button has been released
                        if ((prevButtonMask == currChannelButtonMask) && (currDepthButtonTicks < 12)) {  // short double-click brings back to summary
                            if (currDepthTicks > TICKS_IGNORE_DETAILS) {
                                currDepthTicks = 0;
                            } else {
                                nextDepth = DEPTH_SUMMARY;
                            }
                        } else if (currDepthTicks > TICKS_CLOSE_DETAILS) {  // exit after 1 minute automatically
                            nextDepth = DEPTH_SUMMARY;
                        }
                    } else {
                        if (currChannelButtonMask == currButtonMask) {
                            if (currDepthButtonTicks > TICKS_GOTO_RESET)  {  // held longer than 5 seconds
                                bool isOutputOn = (currOutputs & (0b1 << (currChannel - 1))) != 0;
                                if (isOutputOn) {
                                    nextDepth = DEPTH_PENDING_RESET;
                                } else {
                                    nextDepth = DEPTH_PENDING_OFF;
                                }
                            }
                        } else {
                            ioex_button_led_setAll(currOutputs & 0b00001, currOutputs & 0b00010, currOutputs & 0b00100, currOutputs & 0b01000, currOutputs & 0b10000);  // reset lights
                            switch (currButtonMask) {  // switch to other details
                                case 0b00001: nextDepth = DEPTH_DETAILS; currChannel = 1; break;
                                case 0b00010: nextDepth = DEPTH_DETAILS; currChannel = 2; break;
                                case 0b00100: nextDepth = DEPTH_DETAILS; currChannel = 3; break;
                                case 0b01000: nextDepth = DEPTH_DETAILS; currChannel = 4; break;
                                case 0b10000: nextDepth = DEPTH_DETAILS; currChannel = 5; break;
                            }
                        }
                    }
                } break;

                case DEPTH_PENDING_RESET: {
                    if (currButtonMask == 0) {  // button has been released
                        nextOutputs = resetOutput(currChannel, nextOutputs);
                        nextDepth = DEPTH_PENDING_NOTHING;
                    } else if (currChannelButtonMask == currButtonMask) {
                        if (currDepthButtonTicks > TICKS_WAIT_RESET)  {  // held longer than 5 seconds
                            nextDepth = DEPTH_PENDING_OFF;
                        }
                    }
                } break;

                case DEPTH_PENDING_OFF: {
                    if (currButtonMask == 0) {  // button has been released
                        nextOutputs = toggleOutputMask(currChannel, nextOutputs);
                        nextDepth = DEPTH_PENDING_NOTHING;
                    } else if (currChannelButtonMask == currButtonMask) {
                        if (currDepthButtonTicks > TICKS_WAIT_OFF)  {  // held longer than 3 seconds
                            nextDepth = DEPTH_PENDING_NOTHING;
                        }
                    }
                } break;

                case DEPTH_PENDING_NOTHING: {
                    if (currButtonMask == 0) {  // button has been released
                        nextDepth = DEPTH_SUMMARY;
                    }
                } break;
            }

            // update display twice a second
            if ((tickCounter == 0) || (tickCounter == 12)) {
                io_led_activity_on();

                if (lastActionTicks > TICKS_DISPLAY_OFF) {
                    lastActionTicks = TICKS_DISPLAY_OFF;  // to avoid overflow
                    oled_displayOff();
                } else {  // display stays on
                    oled_displayOn();
                    switch (currDepth) {
                        case DEPTH_SUMMARY: {
                            oled_writeSummary(voltage1, current1, voltage2, current2, voltage3, current3, voltage4, current4, voltage5, current5, temperature, currOutputs);
                        } break;

                        case DEPTH_DETAILS:
                        case DEPTH_PENDING_RESET:
                        case DEPTH_PENDING_OFF:
                        case DEPTH_PENDING_NOTHING: {
                            switch (currChannel) {
                                case 1: {
                                    oled_writeChannel(1, voltage1, current1, currOutputs & 0b00001, currDepth, currDepthButtonTicks);
                                } break;
                                case 2: {
                                    oled_writeChannel(2, voltage2, current2, currOutputs & 0b00010, currDepth, currDepthButtonTicks);
                                } break;
                                case 3: {
                                    oled_writeChannel(3, voltage3, current3, currOutputs & 0b00100, currDepth, currDepthButtonTicks);
                                } break;
                                case 4: {
                                    oled_writeChannel(4, voltage4, current4, currOutputs & 0b01000, currDepth, currDepthButtonTicks);
                                } break;
                                case 5: {
                                    oled_writeChannel(5, voltage5, current5, currOutputs & 0b10000, currDepth, currDepthButtonTicks);
                                } break;
                            }

                        } break;
                    }
                }
            } else if ((tickCounter == 6) || (tickCounter == 18)) {  // prepare UART twice a second
                uartbuffers_txReset();
                fillUartFromChannel(1, voltage1, current1, (currOutputs & 0b00001) > 0);
                fillUartFromChannel(2, voltage2, current2, (currOutputs & 0b00010) > 0);
                fillUartFromChannel(3, voltage3, current3, (currOutputs & 0b00100) > 0);
                fillUartFromChannel(4, voltage4, current4, (currOutputs & 0b01000) > 0);
                fillUartFromChannel(5, voltage5, current5, (currOutputs & 0b10000) > 0);
                fillUartFromTemperature(temperature);
            }
        }
    }
}

void fillUartFromChannel(uint8_t index, uint16_t voltage, uint16_t current, bool isOn) {
    uint32_t power = (uint32_t)voltage * (uint32_t)current / 1000;

    uartbuffers_txAppend(0x30 + index);
    uartbuffers_txAppend(':');
    uartbuffers_txAppend(' ');

    uint8_t buffer[5];
    uint8_t bufferIndex;

    voltage /= 10;  // we don't need mV
    bufferIndex = sizeof(buffer);
    while (bufferIndex > 0) {
        bufferIndex--;
        buffer[bufferIndex] = 0x30 + (voltage % 10);
        voltage /= 10;
        if ((voltage == 0) && (bufferIndex < 3)) { break; }  // we're past decimal point and there are no more digits
    }
    for (uint8_t i = 1; i < sizeof(buffer); i++) {
        if (i < bufferIndex) {
            uartbuffers_txAppend(' ');
        } else {
            uartbuffers_txAppend(buffer[i]);
            if (i == 2) { uartbuffers_txAppend('.'); }
        }
    }
    uartbuffers_txAppend('V');
    uartbuffers_txAppend(' ');
    
    current /= 10;  // we don't need mA
    bufferIndex = sizeof(buffer);
    while (bufferIndex > 0) {
        bufferIndex--;
        buffer[bufferIndex] = 0x30 + (current % 10);
        current /= 10;
        if ((current == 0) && (bufferIndex < 3)) { break; }  // we're past decimal point and there are no more digits
    }
    for (uint8_t i = 2; i < sizeof(buffer); i++) {
        if (i < bufferIndex) {
            uartbuffers_txAppend(' ');
        } else {
            uartbuffers_txAppend(buffer[i]);
            if (i == 2) { uartbuffers_txAppend('.'); }
        }
    }
    uartbuffers_txAppend('A');
    uartbuffers_txAppend(' ');

    power /= 10;  // we don't need mW
    bufferIndex = sizeof(buffer);
    while (bufferIndex > 0) {
        bufferIndex--;
        buffer[bufferIndex] = 0x30 + (power % 10);
        power /= 10;
        if ((power == 0) && (bufferIndex < 3)) { break; }  // we're past decimal point and there are no more digits
    }
    for (uint8_t i = 0; i < sizeof(buffer); i++) {
        if (i < bufferIndex) {
            uartbuffers_txAppend(' ');
        } else {
            uartbuffers_txAppend(buffer[i]);
            if (i == 2) { uartbuffers_txAppend('.'); }
        }
    }
    uartbuffers_txAppend('W');
    uartbuffers_txAppend(' ');

    uartbuffers_txAppend('[');
    if (isOn) {
        uartbuffers_txAppend('O');
        uartbuffers_txAppend('N');
    } else {
        uartbuffers_txAppend('O');
        uartbuffers_txAppend('F');
        uartbuffers_txAppend('F');
    }
    uartbuffers_txAppend(']');

    uartbuffers_txAppend('\r');
    uartbuffers_txAppend('\n');
}

void fillUartFromTemperature(uint16_t temperature) {
    uartbuffers_txAppend('T');
    uartbuffers_txAppend(':');
    uartbuffers_txAppend(' ');

    uint8_t buffer[3];
    uint8_t bufferIndex;

    bufferIndex = sizeof(buffer);
    while (bufferIndex > 0) {
        bufferIndex--;
        buffer[bufferIndex] = 0x30 + (temperature % 10);
        temperature /= 10;
        if ((temperature == 0) && (bufferIndex < 2)) { break; }  // we're past decimal point and there are no more digits
    }
    for (uint8_t i = 0; i < sizeof(buffer); i++) {
        if (i < bufferIndex) {
            uartbuffers_txAppend(' ');
        } else {
            uartbuffers_txAppend(buffer[i]);
            if (i == 1) { uartbuffers_txAppend('.'); }
        }
    }
    uartbuffers_txAppend('C');

    uartbuffers_txAppend('\r');
    uartbuffers_txAppend('\n');
}
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

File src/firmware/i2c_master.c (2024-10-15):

/* Josip Medved <jmedved@jmedved.com> * www.medo64.com * MIT License */

#include <xc.h>
#include <stdbool.h>
#include <stdint.h>
#include "app.h"
#include "i2c_master.h"

#if defined(_I2C_MASTER_CUSTOM_INIT)
    void i2c_master_init(uint8_t rate) {
        #if defined(_I2C_MASTER_MODULE2)  // I2C2 (SCL RB1) (SDA RB2)

            #define I2C_MASTER_I2CCON0_REGISTER         I2C2CON0bits
            #define I2C_MASTER_I2CCON1_REGISTER         I2C2CON1bits
            #define I2C_MASTER_I2CCON2_REGISTER         I2C2CON2bits
            #define I2C_MASTER_I2CCLK_REGISTER          I2C2CLKbits

            #define I2C_MASTER_I2CSTAT0_REGISTER        I2C2STAT0bits
            #define I2C_MASTER_I2CSTAT1_REGISTER        I2C2STAT1bits
            #define I2C_MASTER_I2CADB1_REGISTER         I2C2ADB1
            #define I2C_MASTER_I2CCNT_REGISTER          I2C2CNT
            #define I2C_MASTER_I2CRXB_REGISTER          I2C2RXB
            #define I2C_MASTER_I2CTXB_REGISTER          I2C2TXB

        #else  // I2C1 (SCL RC3) (SDA RC4)

            #define I2C_MASTER_I2CCON0_REGISTER         I2C1CON0bits
            #define I2C_MASTER_I2CCON1_REGISTER         I2C1CON1bits
            #define I2C_MASTER_I2CCON2_REGISTER         I2C1CON2bits
            #define I2C_MASTER_I2CCLK_REGISTER          I2C1CLKbits

            #define I2C_MASTER_I2CSTAT0_REGISTER        I2C1STAT0bits
            #define I2C_MASTER_I2CSTAT1_REGISTER        I2C1STAT1bits
            #define I2C_MASTER_I2CADB1_REGISTER         I2C1ADB1
            #define I2C_MASTER_I2CCNT_REGISTER          I2C1CNT
            #define I2C_MASTER_I2CRXB_REGISTER          I2C1RXB
            #define I2C_MASTER_I2CTXB_REGISTER          I2C1TXB

        #endif

        // Setup I2C
        I2C_MASTER_I2CCON1_REGISTER.ACKCNT = 1;    // Acknowledge value transmitted after received data, when I2CxCNT = 0 - NACK

        T6CLK = 0b0010;                            // Fosc
        if (rate < 10) {
            T6PR = (uint8_t)((uint32_t)_XTAL_FREQ / 4 / 100000 - 1);
        } else if (rate > 100) {
            T6PR = (uint8_t)((uint32_t)_XTAL_FREQ / 4 / 1000000 - 1);
        } else {
            T6PR = (uint8_t)((uint32_t)_XTAL_FREQ / 4 / rate / 10000 - 1);  // Fosc / 5(FME=0) / KHz - 1
        }
        T6HLT = 0x00;                              // pre not sync, rising edge, clk not sync, SW ctrl
        T6CONbits.ON = 1;                          // Timer6 is On
        I2C_MASTER_I2CCLK_REGISTER.CLK = 0b1000;   // Timer6 post scaled output
        I2C_MASTER_I2CCON2_REGISTER.FME = 1;       // SCL is sampled high once before driving SCL low. (FSCL = FI2CXCLK/4)

        I2C_MASTER_I2CCON2_REGISTER.ABD = 0;       // Received address data is loaded only into the I2CxADB; Transmitted address data is loaded from the I2CxADB0/1 registers.
        I2C_MASTER_I2CCON2_REGISTER.BFRET = 0b00;  // 8 I2C Clock pulses (bus free)

        I2C_MASTER_I2CCON0_REGISTER.MODE = 0b100;  // I2C Master mode, 7-bit address
        I2C_MASTER_I2CCON0_REGISTER.EN = 1;        // Enables the I2C module

        #if defined(_I2C_MASTER_MODULE2)  // I2C2
            I2C2PIR = 0x0;
            I2C2PIE = 0x0;
            I2C2ERR = 0x0;
            I2C2CNT = 0x0;
            I2C2PIEbits.SCIE = 0;  // errata
            I2C2PIEbits.PCIE = 0;
        #else  // I2C1
            I2C1PIR = 0x0;
            I2C1PIE = 0x0;
            I2C1ERR = 0x0;
            I2C1CNT = 0x0;
            I2C1PIEbits.SCIE = 0;  // errata
            I2C1PIEbits.PCIE = 0;
        #endif
    }
#else
    void i2c_master_init(void) {
        #if defined(_I2C_MASTER_MODULE2)  // I2C2 (SCL RB1) (SDA RB2)

            #define I2C_MASTER_I2CCON0_REGISTER         I2C2CON0bits
            #define I2C_MASTER_I2CCON1_REGISTER         I2C2CON1bits
            #define I2C_MASTER_I2CCON2_REGISTER         I2C2CON2bits
            #define I2C_MASTER_I2CCLK_REGISTER          I2C2CLKbits

            #define I2C_MASTER_I2CSTAT0_REGISTER        I2C2STAT0bits
            #define I2C_MASTER_I2CSTAT1_REGISTER        I2C2STAT1bits
            #define I2C_MASTER_I2CADB1_REGISTER         I2C2ADB1
            #define I2C_MASTER_I2CCNT_REGISTER          I2C2CNT
            #define I2C_MASTER_I2CRXB_REGISTER          I2C2RXB
            #define I2C_MASTER_I2CTXB_REGISTER          I2C2TXB

        #else  // I2C1 (SCL RC3) (SDA RC4)

            #define I2C_MASTER_I2CCON0_REGISTER         I2C1CON0bits
            #define I2C_MASTER_I2CCON1_REGISTER         I2C1CON1bits
            #define I2C_MASTER_I2CCON2_REGISTER         I2C1CON2bits
            #define I2C_MASTER_I2CCLK_REGISTER          I2C1CLKbits

            #define I2C_MASTER_I2CSTAT0_REGISTER        I2C1STAT0bits
            #define I2C_MASTER_I2CSTAT1_REGISTER        I2C1STAT1bits
            #define I2C_MASTER_I2CADB1_REGISTER         I2C1ADB1
            #define I2C_MASTER_I2CCNT_REGISTER          I2C1CNT
            #define I2C_MASTER_I2CRXB_REGISTER          I2C1RXB
            #define I2C_MASTER_I2CTXB_REGISTER          I2C1TXB

        #endif

        // Setup I2C
        I2C_MASTER_I2CCON1_REGISTER.ACKCNT = 1;       // Acknowledge value transmitted after received data, when I2CxCNT = 0 - NACK
        #if defined(_I2C_MASTER_RATE_KHZ)
            T6CLK = 0b0010;                           // Fosc
            T6PR = _XTAL_FREQ / 4 / _I2C_MASTER_RATE_KHZ / 1000 - 1;  // Fosc / 5(FME=0) / KHz - 1
            T6HLT = 0x00;                             // pre not sync, rising edge, clk not sync, SW ctrl
            T6CONbits.ON = 1;                         // Timer6 is On
            I2C_MASTER_I2CCLK_REGISTER.CLK = 0b1000;  // Timer6 post scaled output
            I2C_MASTER_I2CCON2_REGISTER.FME = 1;      // SCL is sampled high once before driving SCL low. (FSCL = FI2CXCLK/4)
        #else
            I2C_MASTER_I2CCLK_REGISTER.CLK = 0b0011;  // MFINTOSC (500 kHz)
            I2C_MASTER_I2CCON2_REGISTER.FME = 0;      // SCL is sampled high twice before driving SCL low. (FSCL = FI2CXCLK/5)
        #endif
        I2C_MASTER_I2CCON2_REGISTER.ABD = 0;          // Received address data is loaded only into the I2CxADB; Transmitted address data is loaded from the I2CxADB0/1 registers.
        I2C_MASTER_I2CCON2_REGISTER.BFRET = 0b00;     // 8 I2C Clock pulses (bus free)

        I2C_MASTER_I2CCON0_REGISTER.MODE = 0b100;     // I2C Master mode, 7-bit address
        I2C_MASTER_I2CCON0_REGISTER.EN = 1;           // Enables the I2C module

        #if defined(_I2C_MASTER_MODULE2)  // I2C2
            I2C2PIR = 0x0;
            I2C2PIE = 0x0;
            I2C2ERR = 0x0;
            I2C2CNT = 0x0;
            I2C2PIEbits.SCIE = 0;  // errata
            I2C2PIEbits.PCIE = 0;
        #else  // I2C1
            I2C1PIR = 0x0;
            I2C1PIE = 0x0;
            I2C1ERR = 0x0;
            I2C1CNT = 0x0;
            I2C1PIEbits.SCIE = 0;  // errata
            I2C1PIEbits.PCIE = 0;
        #endif
    }
#endif
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

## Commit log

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2024-08-17 Added aluminium plate model
    [Aluminium Plate.FCStd]
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2024-08-17 Fancontroller supports 4 fans
    [FanController.kicad_pcb]
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2024-08-19 Changed DellTrigger diode to zener
    [DellTrigger.kicad_pcb]
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2024-08-20 Fixed hole diameter to 2.5mm
    [AuxPower1U Aluminium Plate.FCStd]
2024-08-21 Replaced MCP9700A with MCP9701A
    [FanController.kicad_pcb, FanController.kicad_sch]
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2024-08-23 Adjusted resistors a bit
    [AuxPower.kicad_pcb]
2024-08-23 Swapped PIC for SOIC variant
    [AuxPower.kicad_pcb]
2024-08-23 Fixed fan connector count on FanController
2024-08-27 Moved silkscreen descriptions a bit
    [AuxPower.kicad_pcb]
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2024-08-27 Updated models to have PTH holes on both sides
    [FanController.kicad_pcb]
2024-08-27 Updated PTH components to have soldermask opening on both sides
    [AuxPower.kicad_pcb]
2024-08-27 Moved GND line to look nicer
    [AuxPower.kicad_pcb]
2024-08-29 Increasing resistors to account for 55V supply
    [AuxPower.kicad_pcb]
2024-08-29 Redesigned FanController board
    [FanController.kicad_pcb]
2024-08-30 Added AC grommet model
    [AuxPower1U AC Grommet.FCStd, AuxPower1U AC Grommet.stl]
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2024-09-01 Updated oled chasis tolerances
    [AuxPower1U OLED.FCStd]
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2024-09-07 Additional OLED model update
    [AuxPower1U OLED.FCStd]
2024-09-09 Added shroud to alignment blocks
    [AuxPower1U Holes.FCStd]
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2024-09-11 Renamed drill template file
    [AuxPower1U Drill Template.FCStd]
2024-09-12 Resizing PS retainers a bit
    [AuxPower1U Retainers.FCStd]
2024-09-12 Added chamfer to PS clips top
    [AuxPower1U Retainers.FCStd]
2024-09-12 A bit more messing with PS retainers
    [AuxPower1U Retainers.FCStd]
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2024-09-14 Updated PS rails to be full length
    [AuxPower1U PSRail.FCStd, AuxPower1U Retainers.FCStd]
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2024-09-14 Add fan back brace (needs rework)
    [AuxPower1U Fan.FCStd]
2024-09-14 Updated DC drill template
    [AuxPower1U Drill Template.FCStd]
2024-09-14 Added alu plate fixup
    [AuxPower1U Aluminium Plate Fixup.FCStd]
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2024-09-15 Adjusted drill template for DC
    [AuxPower1U Drill Template.FCStd]
2024-09-15 Added PCB case models
    [AuxPower1U PCBs.FCStd]
2024-09-15 Changed drill size for aluminium plate
    [AuxPower1U Aluminium Plate Fixup.FCStd, AuxPower1U Aluminium Plate.FCStd]
2024-09-15 Refactoring PCB retainer model
    [AuxPower1U PCBs.FCStd]
2024-09-16 Added stopped to OLED model
    [AuxPower1U OLED.FCStd]
2024-09-16 Added fixup for audio 3.5mm jack
    [AuxPower1U Fixup.FCStd]
2024-09-17 Adjusted depth for main controller box
    [AuxPower1U PCBs.FCStd]
2024-09-17 Deeper cutouts for edge connectors
    [AuxPower1U PCBs.FCStd]
2024-09-17 Cutting edges some more
    [AuxPower1U PCBs.FCStd]
2024-09-17 More adjusting for PCB boxes
    [AuxPower1U PCBs.FCStd]
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2024-09-22 Adjusted rail model to have pass-through for fan wires
    [AuxPower1U PSRail.FCStd]
2024-09-22 MainController: Moved Activity LED a bit
    [AuxPower.kicad_pcb]
2024-09-23 Shortening code a bit
    [i2c_master.c]
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2024-09-26 MainController: Adding forgotten 1K to GND for current monitor
    [AuxPower.kicad_pcb]
2024-09-26 MainController: adjusting trace widths a bit
    [AuxPower.kicad_pcb]
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2024-09-29 MainController: making output open-drain
    [AuxPower.kicad_pcb]
2024-09-29 MainController: Changed transistor base resistor to 10K
    [AuxPower.kicad_pcb]
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2024-09-29 MainController: Changed ZXCT1009 to HV7801
    [AuxPower.kicad_pcb]
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2024-09-29 MainController: moved UART lines
    [AuxPower.kicad_pcb]
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2024-10-02 MainController: fixing LEDs after reset from off state
    [app.c]
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2024-10-03 MainController: adjusting voltage dividers
    [AuxPower.kicad_pcb]
2024-10-06 FanController: Both 1x4 and 2x2 variants available
    [FanController.kicad_pcb, FanController.kicad_sch]
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2024-10-13 MainController: fixed display bug
    [app.c]
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2024-10-17 MainController: Replaced main mosfet
    [AuxPower.kicad_pcb]
2024-10-17 MainController: added vent holes to PCB holder
    [AuxPower1U PCBs.FCStd]
2024-10-20 MainController: Refactoring PCB holder bottom pockets
    [AuxPower1U PCBs.FCStd]
2024-10-20 MainController: extra side venting holes
    [AuxPower1U PCBs.FCStd]
2024-10-20 MainController: rounded bottom pockets
    [AuxPower1U PCBs.FCStd]
2024-10-20 MainController: refactoring PCB holder vents
    [AuxPower1U PCBs.FCStd]
2024-10-20 MainController: Adjusted resistor values for MOSFET drive
    [AuxPower.kicad_pcb]
2024-10-20 MainController: Reducing internal LED brightness
    [AuxPower.kicad_pcb]
2024-10-20 MainController: Reducing brightness for output LEDs
    [AuxPower.kicad_pcb]
2024-10-29 MainController: A bit wider side PCB holder
    [AuxPower1U PCBs.FCStd]
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2024-11-03 MainController: Moving voltage for PIC after shunt resistor
    [AuxPower.kicad_pcb]
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2024-11-04 Updated components to match new ratios
    [AuxPower.kicad_pcb]
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2024-11-13 MainController: Added missing trace
    [AuxPower.kicad_pcb]
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2024-11-13 MainController: increased power limit slightly to prevent false triggers
    [app.c]
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2024-11-14 Moved 12V input before sense line
    [AuxPower.kicad_pcb]
2024-11-14 Increased trace width for power
    [AuxPower.kicad_pcb, AuxPowerDummy.kicad_pcb]
2024-11-14 MainController: added extra hole to PCB holder model
    [AuxPower1U PCBs.FCStd]
2024-11-15 MainController: moved ICSP in case model
    [AuxPower1U PCBs.FCStd]
2024-11-15 MainController: smaller side vent
    [AuxPower1U PCBs.FCStd]
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2024-11-15 MainController: added brace hole
    [AuxPower1U PCBs.FCStd]
2024-11-16 MainController: reduces ICSP hole height for PCB case
    [AuxPower1U PCBs.FCStd]
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2024-11-16 MainController: minor corrections to PCB case
    [AuxPower1U PCBs.FCStd]
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2024-11-16 MainController: wider GND traces
    [AuxPower.kicad_pcb]
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2025-01-12 Fixed connector dimensions for NetGear GS305EPP
2025-07-15 Refactoring to use PhotoMOS (not completed)
    [AuxPower.kicad_pcb]
2025-07-15 Reconnected all broken traces
    [AuxPower.kicad_pcb]
2025-07-16 Cleaning up a bit
    [AuxPower.kicad_pcb]
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2025-07-19 Moved fan controller to AuxFanController repo
    [FanController.kicad_pcb, FanController.kicad_sch]
2025-07-19 Migrated DellPowerTrigger to a separate repository
    [DellTrigger.kicad_pcb, DellTrigger.kicad_sch]
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2025-07-25 Refactored the whole board to have switches in airflow direction
    [AuxPower.kicad_pcb]
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2025-07-26 Fixed back rail alignment
    [AuxPower1U.FCStd]
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2025-08-30 Reverse fan mount
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2025-08-30 Fixed output LEDS
    [AuxPower.kicad_pcb]
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2025-08-31 Reverse fan mount (blowing in)
2025-08-31 Swapped OLED pinout to match 128x64 order
    [AuxPower.kicad_pcb]
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2025-09-01 Fixed temperature overflow
2025-09-15 Fixed PhotoMOS refdes
    [AuxPower.kicad_pcb]
2025-09-21 Fixed current monitor part name
    [AuxPower.kicad_pcb]
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2025-09-21 Adjusted reset to show measurement during reset
    [app.c]
